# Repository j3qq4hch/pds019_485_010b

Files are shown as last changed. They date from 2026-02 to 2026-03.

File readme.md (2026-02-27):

# pds019_485_010

В этом репозитории содержатся исходники проекта `pds019_485_010`. Проект включает в себя две платы: A и B.

На плате А располагается модуль esp32, разъемы для его программирования две кнопки и несколько светодиодов.

На плате B располагается система питания устройства, состоящая из AC-DC модуля, создающего шину питания 12в и DC-DC конвертера 12в -> 3.3в. Кроме этого на плате B располагается гальванически изолированный RS485 интерфейс, реле и разъем для подключения датчика. 

# Плата А

<p align = center>
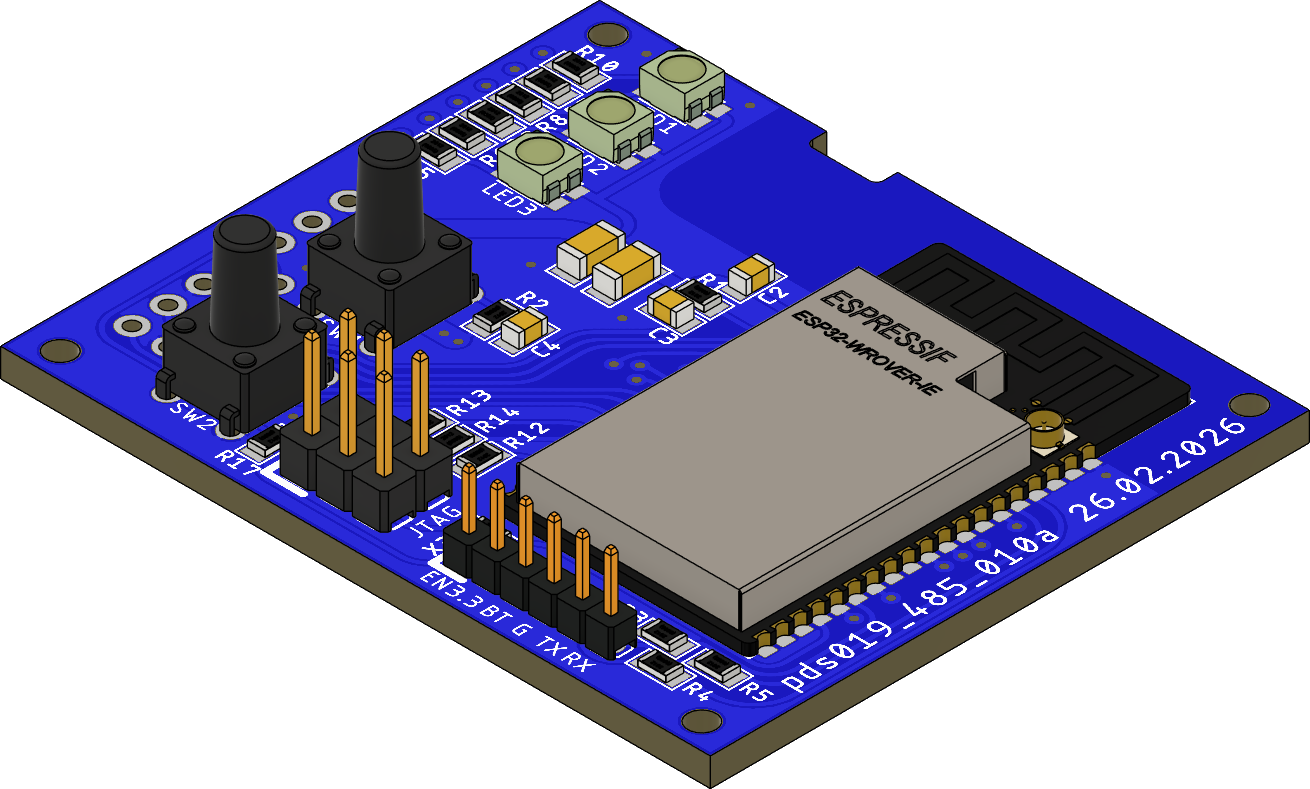
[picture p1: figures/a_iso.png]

</p>

# Плата B
<p align = center>

| Сторона TOP  | Сторона BOTTOM |
|---|---|
|||

</p>

3D модель доступна [по ссылке](https://a360.co/4bcfLyz).
BoM доступен [по ссылке](https://docs.google.com/spreadsheets/d/1rppHGotYg97vevn0TNhSlOjf3by5jG4KPH9rv6CT_tg/edit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).

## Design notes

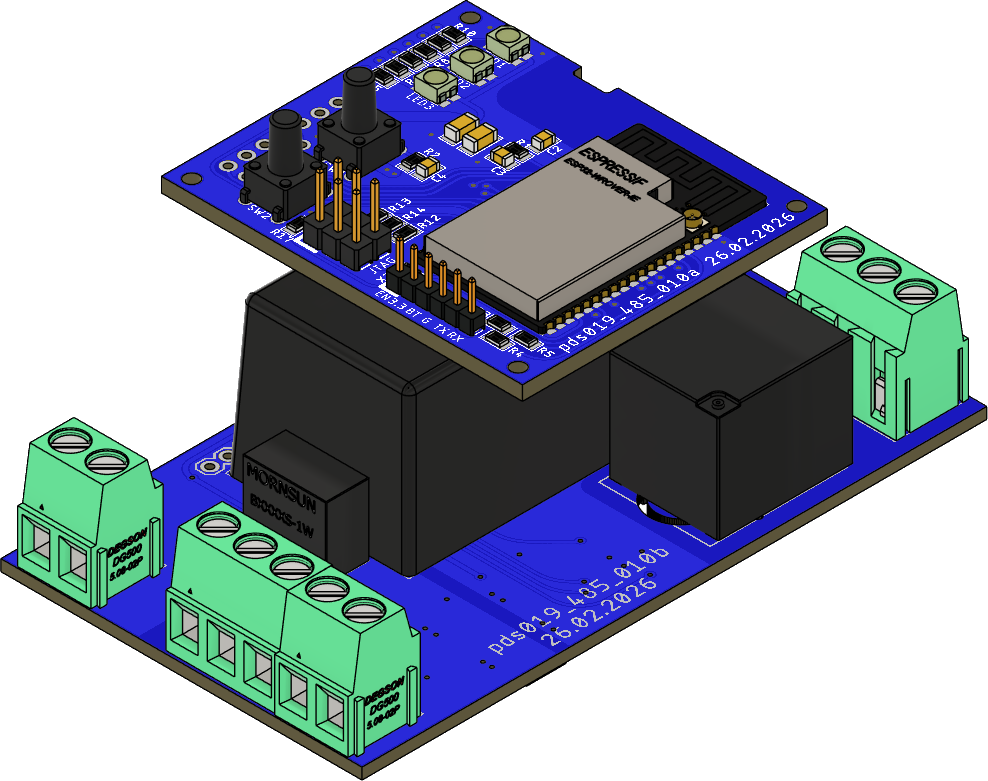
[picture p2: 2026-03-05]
figures/iso_assy.png

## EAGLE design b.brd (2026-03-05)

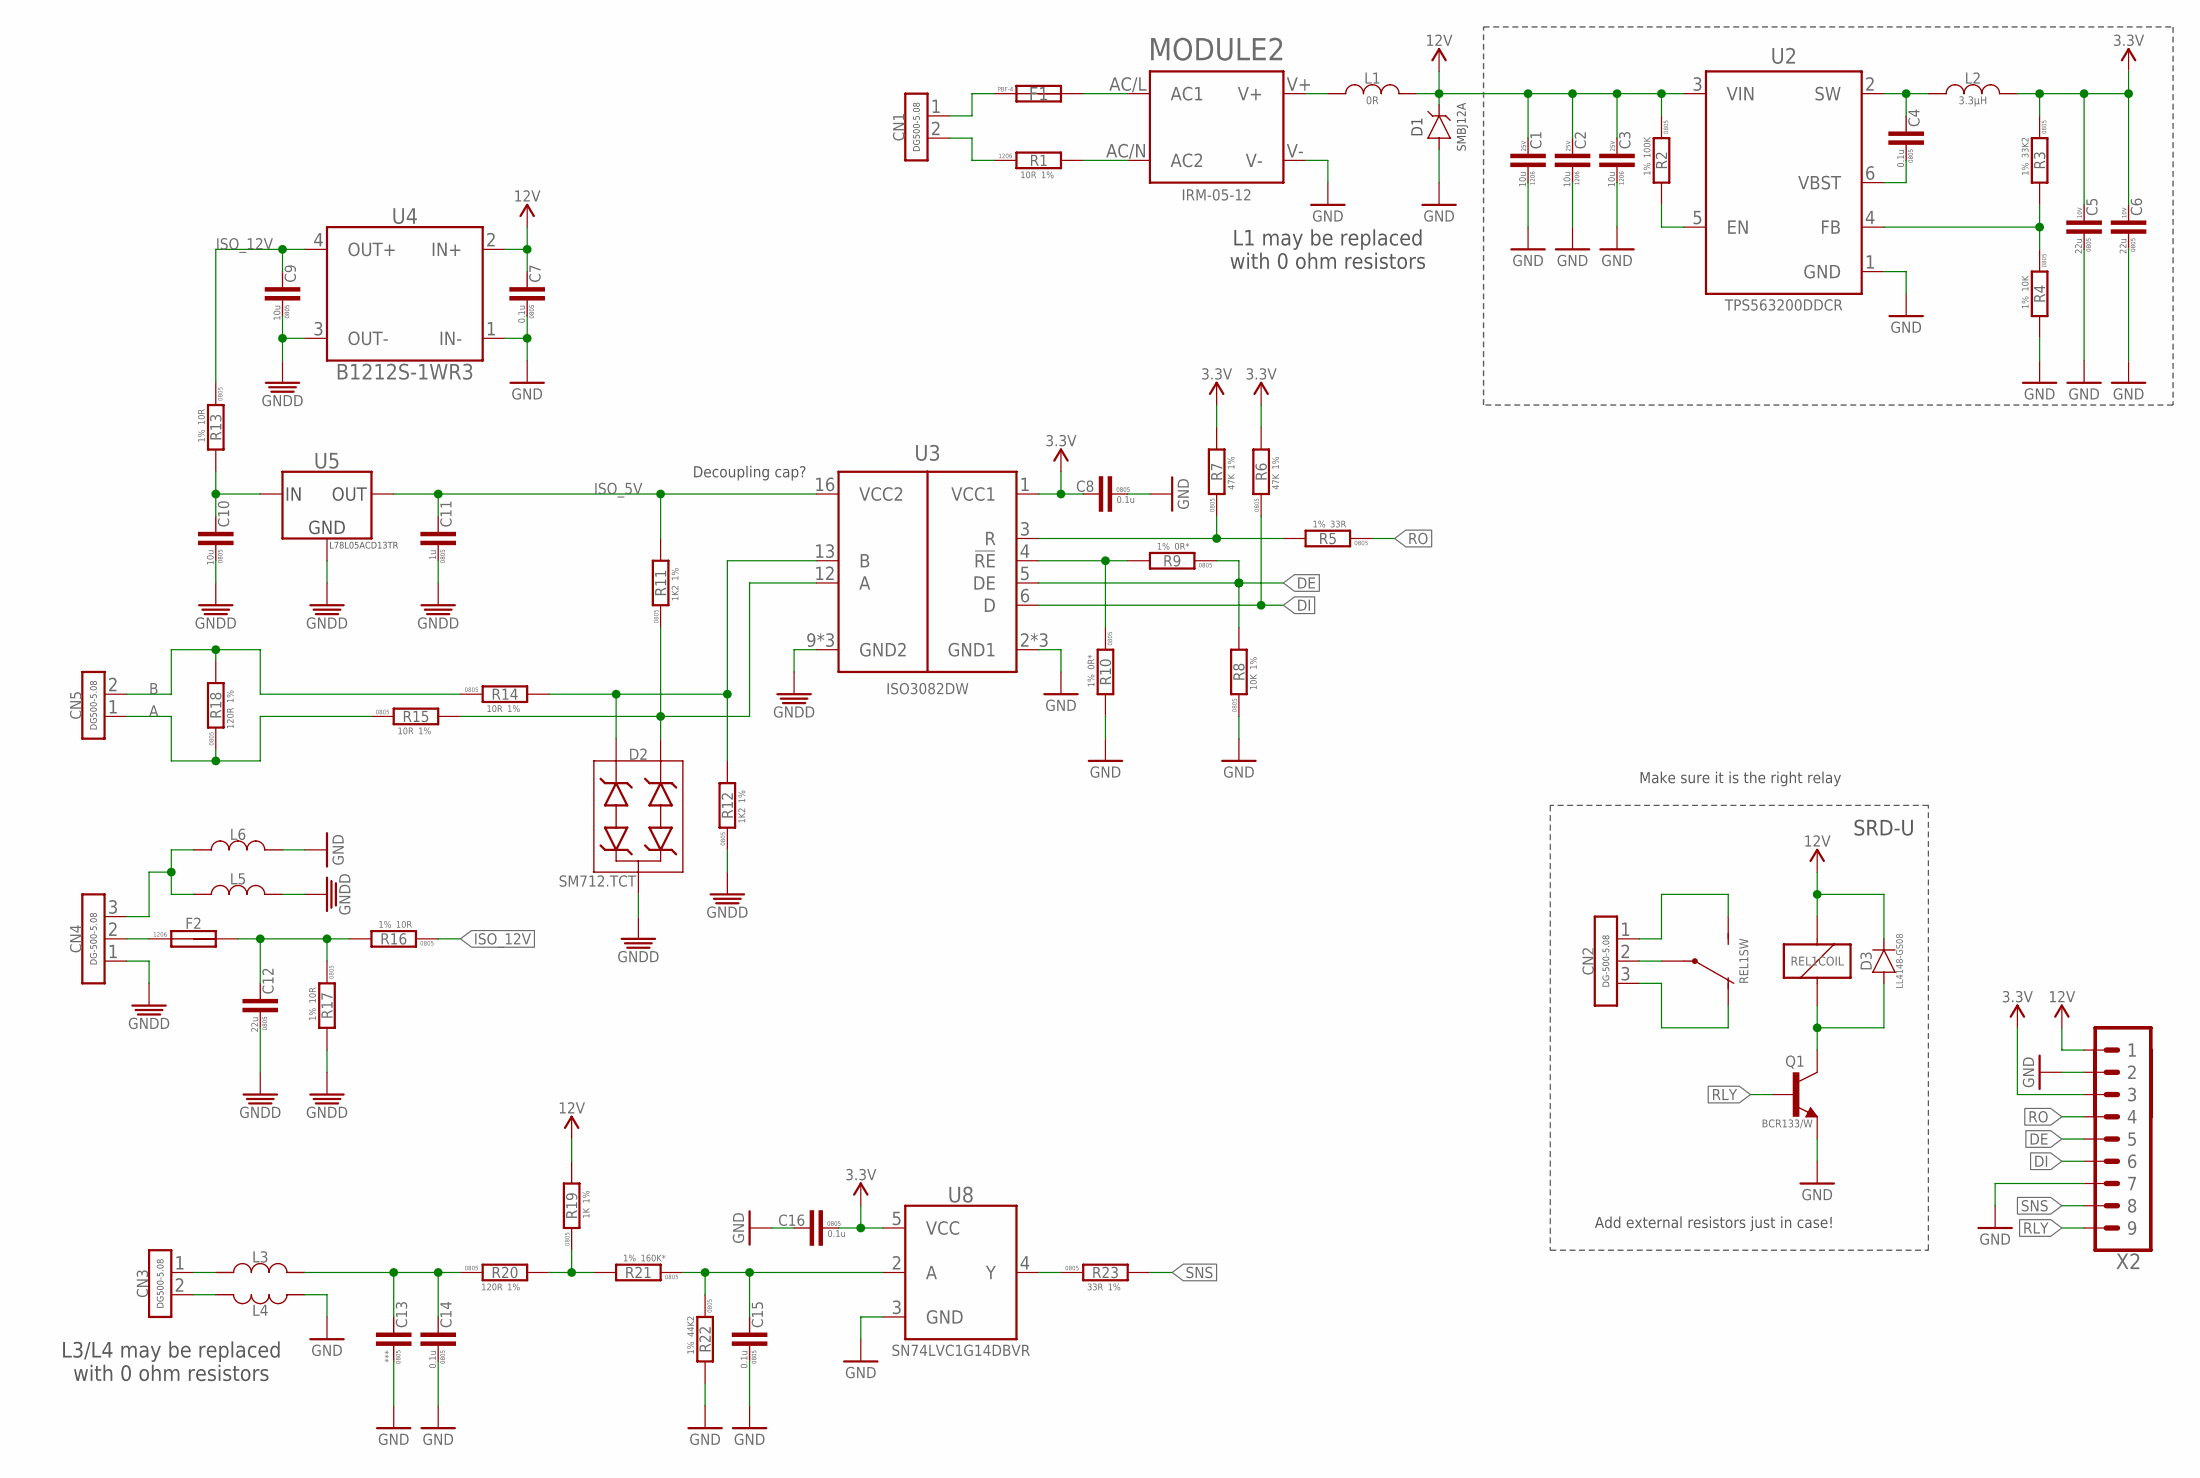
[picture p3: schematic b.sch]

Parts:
C1, C2, C3: 10u; C1206; VOLTAGE 25V
C4, C7, C8, C14, C15, C16: 0.1u; C0805
C5, C6: 22u; C0805; VOLTAGE 10V
C9, C10: 10u; C0805
C11: 1u; C0805
C12: 22u; C0805
C13: ***; C0805
CN1, CN3, CN5: CON-2P-DG500-5.08; DG500-5.08-02P
CN2, CN4: CON-3P-DG500-5.08; DG500-5.08-03P
D1: SMBJ12A-SMB; DO-214AA(SMB)
D2: SM712; SOT23B-3
D3: LL4148; LL-34
F1: 1.6A; MST-FUSE
F2: MF-NSMF050-2; F1206
L1: 0R; L0805
L2: 3.3µH; VLS6045EX
L3, L4, L5, L6: L-0805; L0805
MODULE2: IRM-05-12; IRM-05
Q1: BCR133; SOT23B-3
R1: 10R; R1206
R2: 100K; R0805
R3: 33K2; R0805
R4, R8: 10K; R0805
R5, R23: 33R; R0805
R6, R7: 47K; R0805
R9, R10: 0R*; R0805
R11, R12: 1K2; R0805
R13, R14, R15, R16, R17: 10R; R0805
R18, R20: 120R; R0805
R19: 1K; R0805
R21: 160K*; R0805
R22: 44K2; R0805
REL1: RELAY_SPDTHJR-3FF-SH; HJR-3FF-12VDC-S-Z
U2: TPS563200; SOT23-6
U3: ISO3082; SO-16W
U4: B1212S-1WR3; SIP-4
U5: L78L05ACD13TR; SOIC8
U8: 74LVC1G14DBV; SOT23-5
X2: PINHEAD_1X09-2.54-TH-MALE; 1X09-PTH-2.54

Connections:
3490587: R5.2, R7.1, U3.3 (R)
+12V: CN4.2, F2.P$1 (1)
A: CN5.1, R15.1, R18.1
B: CN5.2, R14.1, R18.2
DE: R8.2, R9.1, U3.5 (DE), X2.5
DI: R6.1, U3.6 (D), X2.6
GND: C1.P$1 (1), C2.P$1 (1), C3.P$1 (1), C5.1, C6.1, C7.1, C8.1, C13.1, C14.1, C15.1, C16.2, D1.A, L4.2, L6.1, MODULE2.V-, Q1.2 (E), R4.2, R8.1, R10.2, R22.2, U2.1 (GND), U3.2 (GND1), U3.7 (GND1), U3.8 (GND1), U4.1 (IN-), U8.3 (GND), X2.2, X2.7
GNDD: C9.1, C10.1, C11.1, C12.1, CN4.1, D2.3, L5.2, R12.1, R17.2, U3.9 (GND2), U3.10 (GND2), U3.15 (GND2), U4.3 (OUT-), U5.2 (GND), U5.3 (GND), U5.6 (GND), U5.7 (GND)
ISO_5V: C11.2, R11.2, U3.16 (VCC2), U5.1 (OUT)
ISO_12V: C9.2, R13.1, R16.1, U4.4 (OUT+)
unnamed: CN4.3, L5.1, L6.2
unnamed: MODULE2.AC/N (AC2), R1.P$2 (2)
unnamed: D2.2 (C2), R11.1, R15.2, U3.12 (A)
unnamed: D2.1 (C3), R12.2, R14.2, U3.13 (B)
unnamed: F1.2, MODULE2.AC/L (AC1)
unnamed: L1.1, MODULE2.V+
unnamed: C4.1, U2.6 (VBST)
unnamed: R9.2, R10.1, U3.4 (!RE)
unnamed: CN1.1, F1.1
unnamed: CN1.2, R1.P$1 (1)
unnamed: R2.2, U2.5 (EN)
unnamed: C4.2, L2.P$1 (1), U2.2 (SW)
unnamed: R3.2, R4.1, U2.4 (FB)
unnamed: CN2.2, REL1.1 (COM)
unnamed: CN2.3, REL1.4 (NC)
unnamed: CN2.1, REL1.3 (NO)
unnamed: CN3.1, L3.1
unnamed: CN3.2, L4.1
unnamed: C13.2, C14.2, L3.2, R20.1
unnamed: C10.2, R13.2, U5.8 (IN)
unnamed: R19.1, R20.2, R21.2
unnamed: C15.2, R21.1, R22.1, U8.2 (A)
unnamed: D3.A, Q1.3 (C), REL1.5 (2)
unnamed: R23.1, U8.4 (Y)
unnamed: C12.2, F2.P$2 (2), R16.2, R17.1
RLY: Q1.1 (B), X2.9
RO: R5.1, X2.4
SNS: R23.2, X2.8
VDD_3V3: C5.2, C6.2, C8.2, C16.1, L2.P$2 (2), R3.1, R6.2, R7.2, U3.1 (VCC1), U8.5 (VCC), X2.3
VDD_12V: C1.P$2 (2), C2.P$2 (2), C3.P$2 (2), C7.2, D1.C, D3.C, L1.2, R2.1, R19.2, REL1.2 (1), U2.3 (VIN), U4.2 (IN+), X2.1

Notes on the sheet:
Add external resistors just in case!
Make sure it is the right relay
Decoupling cap?
SRD-U
L3/L4 may be replaced with 0 ohm resistors
L1 may be replaced with 0 ohm resistors

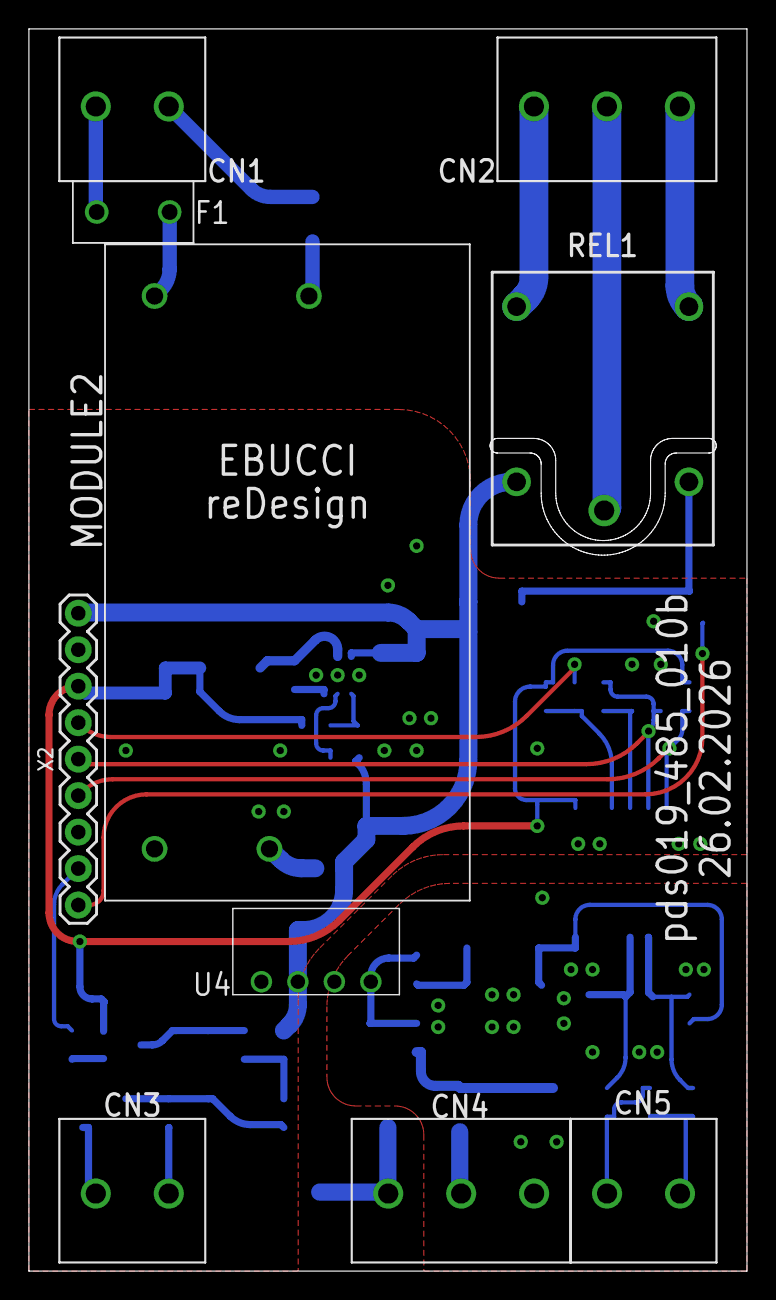
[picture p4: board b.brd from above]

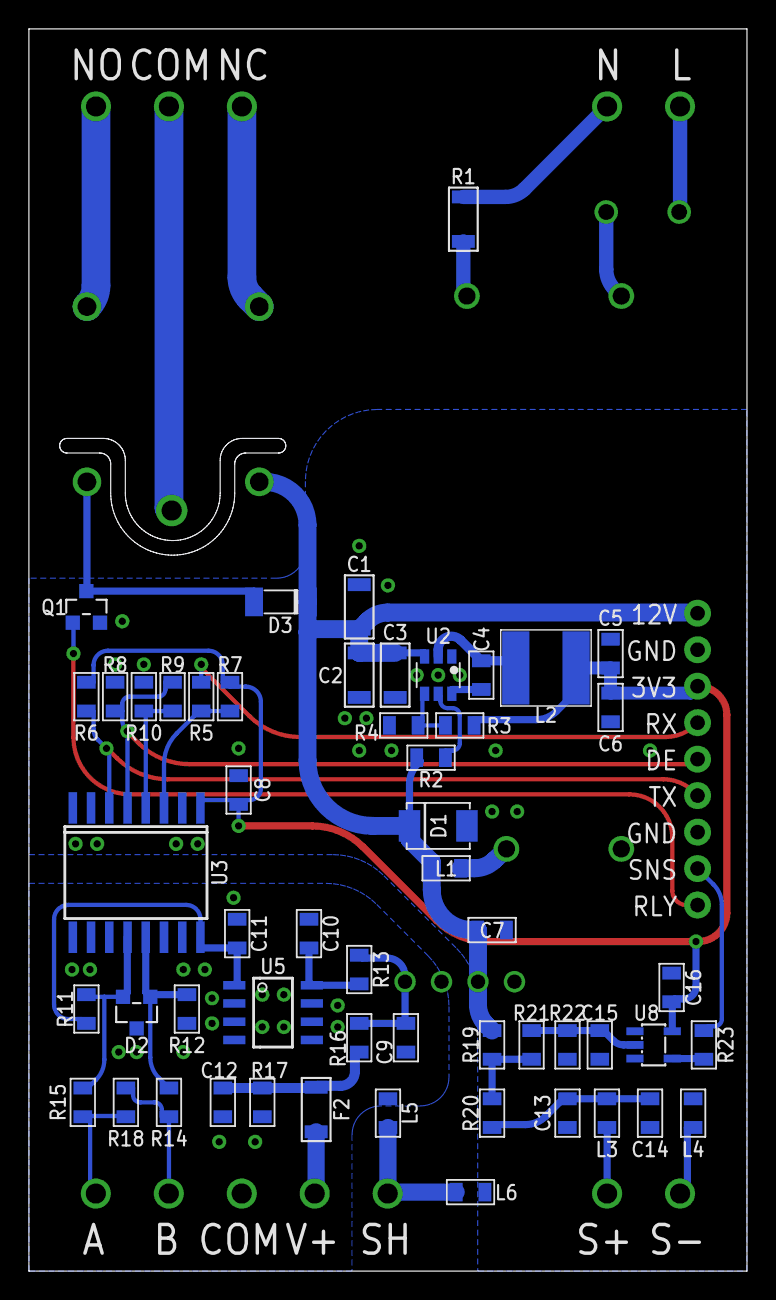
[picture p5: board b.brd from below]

Board: 2 copper layers, 50.0 x 86.5 mm, 65 parts (54 on the bottom side), 40 nets.

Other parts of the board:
U$1: REF_B

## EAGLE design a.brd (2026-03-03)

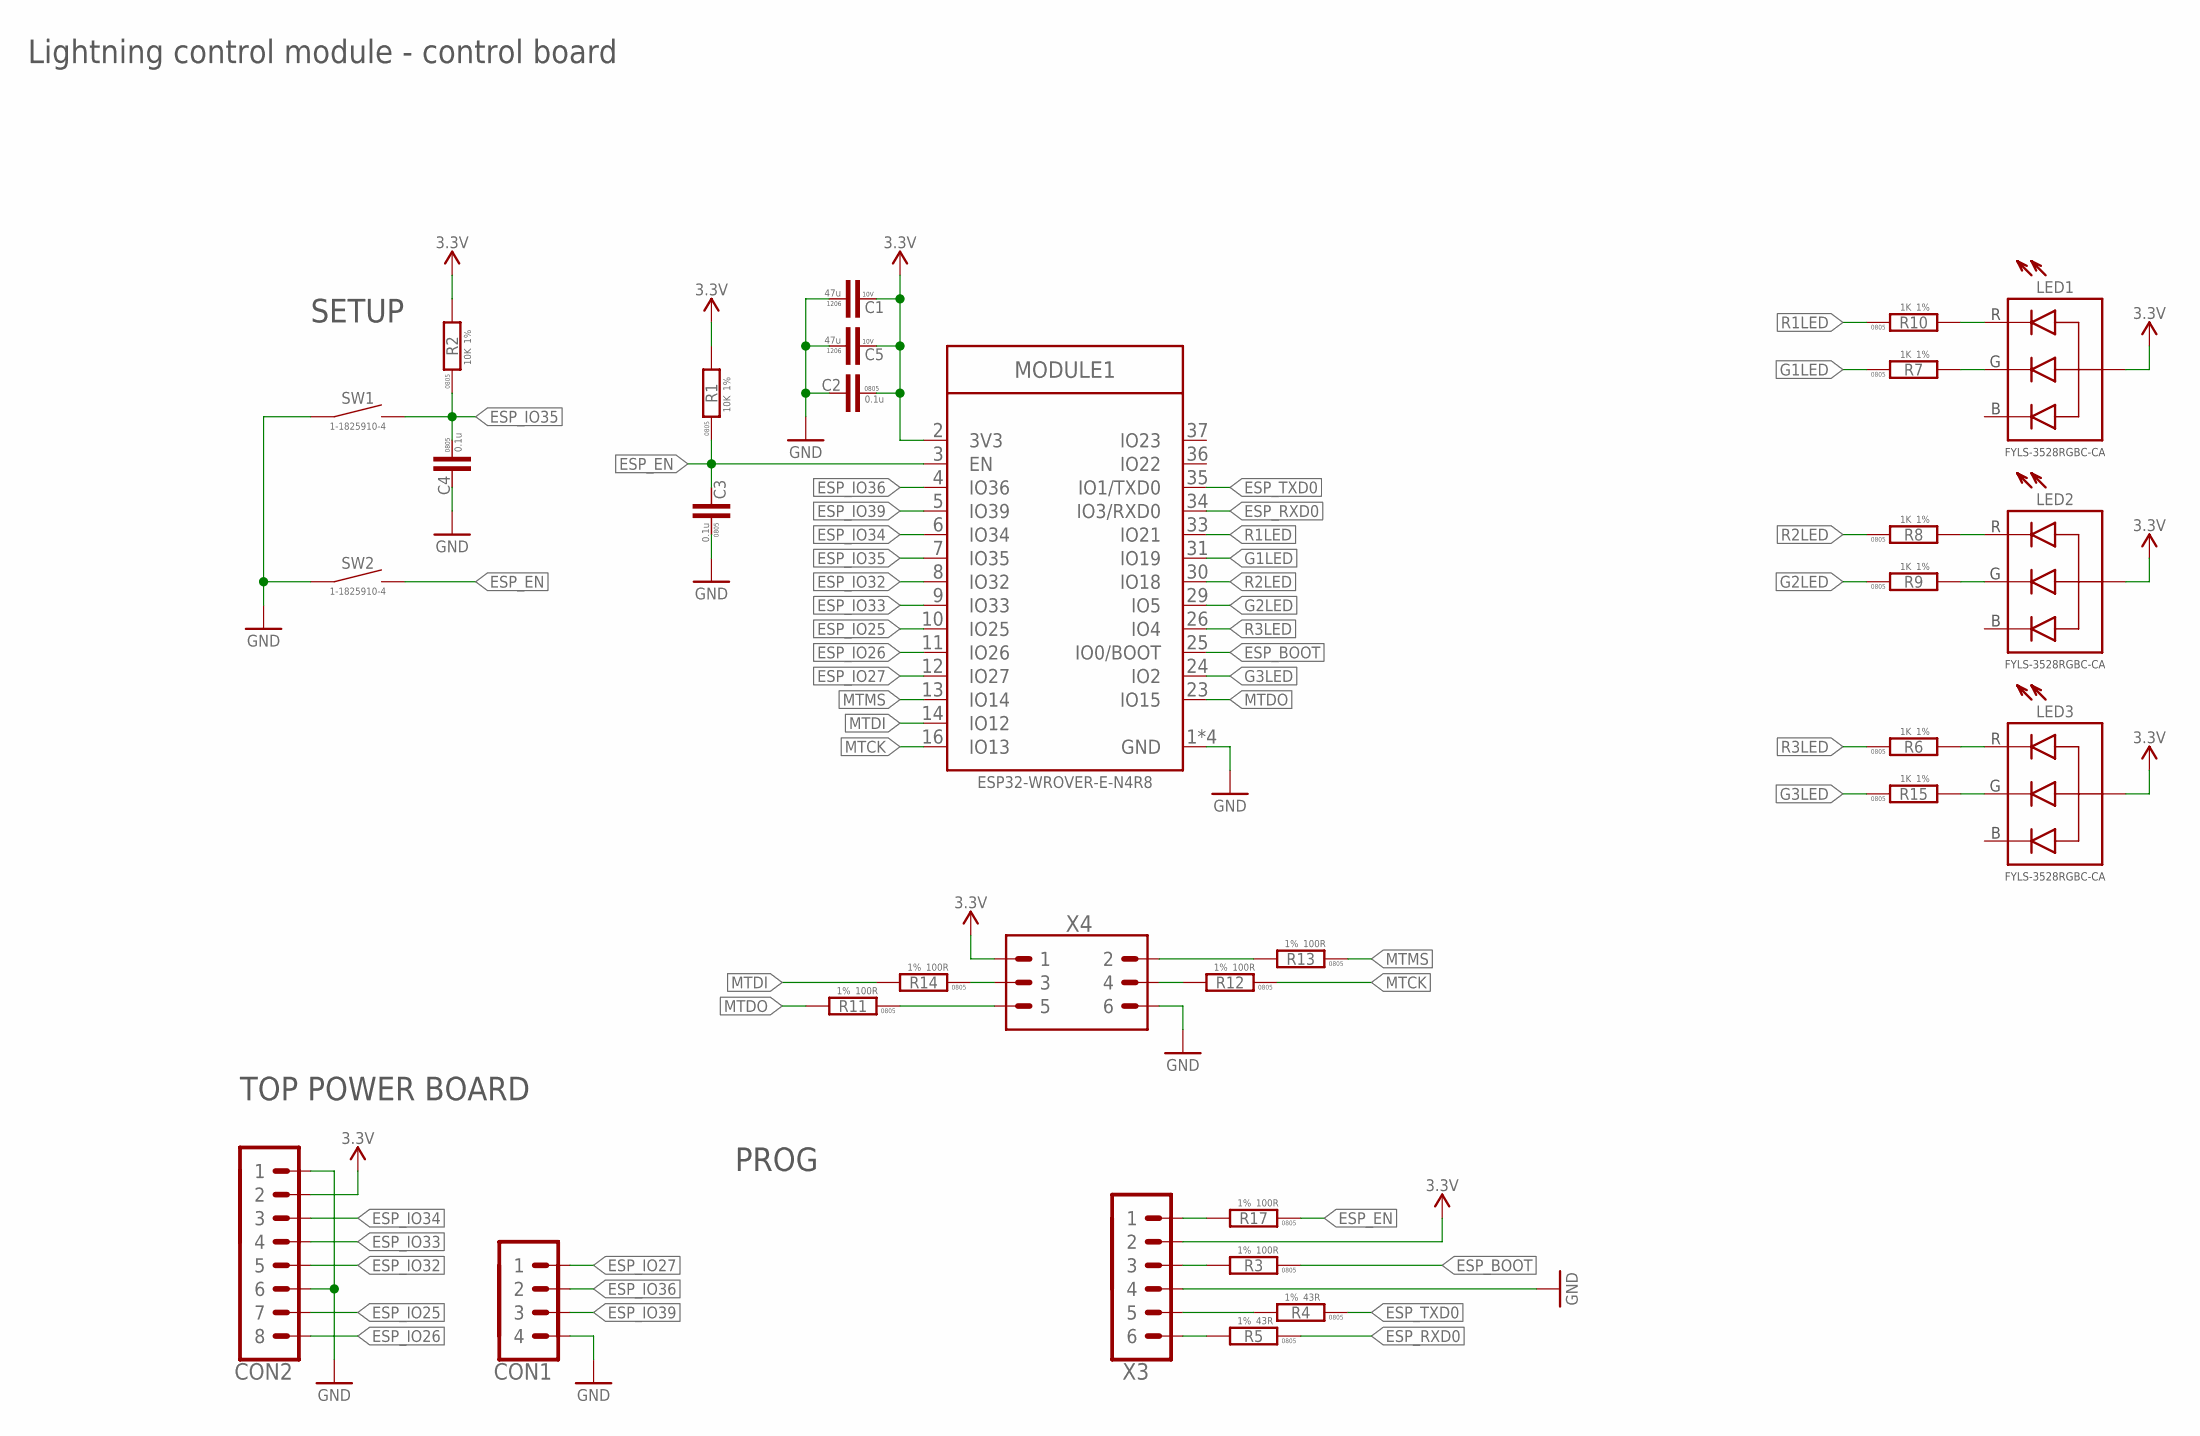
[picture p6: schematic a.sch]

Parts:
C1, C5: 47u; C1206; VOLTAGE 10V
C2, C3, C4: 0.1u; C0805
CON1: PINHEAD_1X04-2.54; 1X04-PTH-2.54
CON2: PINHEAD_1X08-2.54; 1X08-PTH-2.54
LED1, LED2, LED3: LED_RGB-3528; LED3528
MODULE1: ESP32-WROVER-(I)E; ESP32-WROVER-E
R1, R2: 10K; R0805
R3, R11, R12, R13, R14, R17: 100R; R0805
R4, R5: 43R; R0805
R6, R7, R8, R9, R10, R15: 1K; R0805
SW1, SW2: TACT_SWITCH-1-1825910-4; 1-1825910-4
X3: PINHEAD_1X06-2-MALE; 1X06-PTH-2
X4: PINHEAD_2X03-PTH-2.54; 2X03-PTH-2.54

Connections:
ESP_BOOT: MODULE1.25 (IO0/BOOT), R3.1
ESP_EN: C3.2, MODULE1.3 (EN), R1.1, R17.1, SW2.3 (2), SW2.4 (2)
ESP_IO25: CON2.7, MODULE1.10 (IO25)
ESP_IO26: CON2.8, MODULE1.11 (IO26)
ESP_IO27: CON1.1, MODULE1.12 (IO27)
ESP_IO32: CON2.5, MODULE1.8 (IO32)
ESP_IO33: CON2.4, MODULE1.9 (IO33)
ESP_IO34: CON2.3, MODULE1.6 (IO34)
ESP_IO35: C4.1, MODULE1.7 (IO35), R2.1, SW1.3 (2), SW1.4 (2)
ESP_IO36: CON1.2, MODULE1.4 (IO36)
ESP_IO39: CON1.3, MODULE1.5 (IO39)
ESP_RXD0: MODULE1.34 (IO3/RXD0), R5.1
ESP_TXD0: MODULE1.35 (IO1/TXD0), R4.1
G1LED: MODULE1.31 (IO19), R7.1
G2LED: MODULE1.29 (IO5), R9.1
G3LED: MODULE1.24 (IO2), R15.1
GND: C1.P$1 (1), C2.2, C3.1, C4.2, C5.P$1 (1), CON1.4, CON2.1, CON2.6, MODULE1.1 (GND), MODULE1.15 (GND), MODULE1.38 (GND), MODULE1.39 (GND), SW1.1, SW1.2 (1), SW2.1, SW2.2 (1), X3.4, X4.6
MTCK: MODULE1.16 (IO13), R12.1
MTDI: MODULE1.14 (IO12), R14.2
MTDO: MODULE1.23 (IO15), R11.2
MTMS: MODULE1.13 (IO14), R13.1
unnamed: LED2.1 (R), R8.2
unnamed: R13.2, X4.2
unnamed: R5.2, X3.6
unnamed: R4.2, X3.5
unnamed: R3.2, X3.3
unnamed: R12.2, X4.4
unnamed: LED1.1 (R), R10.2
unnamed: LED1.4 (G), R7.2
unnamed: LED2.4 (G), R9.2
unnamed: LED3.1 (R), R6.2
unnamed: LED3.4 (G), R15.2
unnamed: R14.1, X4.3
unnamed: R11.1, X4.5
unnamed: R17.2, X3.1
R1LED: MODULE1.33 (IO21), R10.1
R2LED: MODULE1.30 (IO18), R8.1
R3LED: MODULE1.26 (IO4), R6.1
VDD_3V3: C1.P$2 (2), C2.1, C5.P$2 (2), CON2.2, LED1.2 (A), LED2.2 (A), LED3.2 (A), MODULE1.2 (3V3), R1.2, R2.2, X3.2, X4.1

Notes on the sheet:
Lightning control module - control board
SETUP
PROG
TOP POWER BOARD

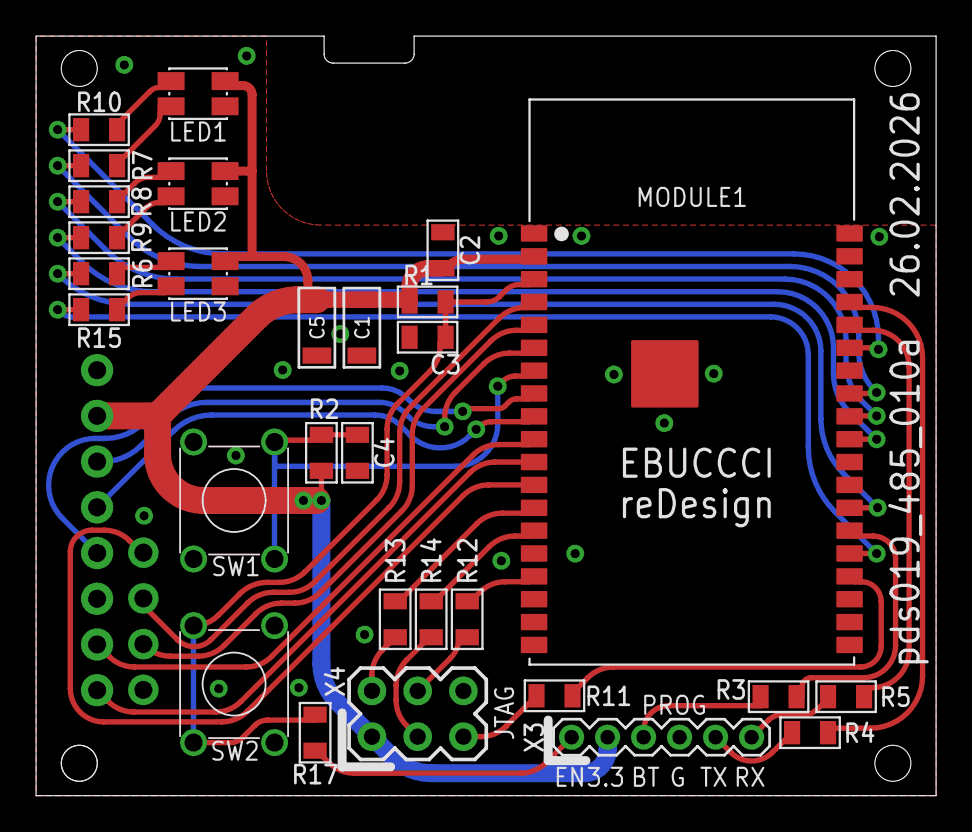
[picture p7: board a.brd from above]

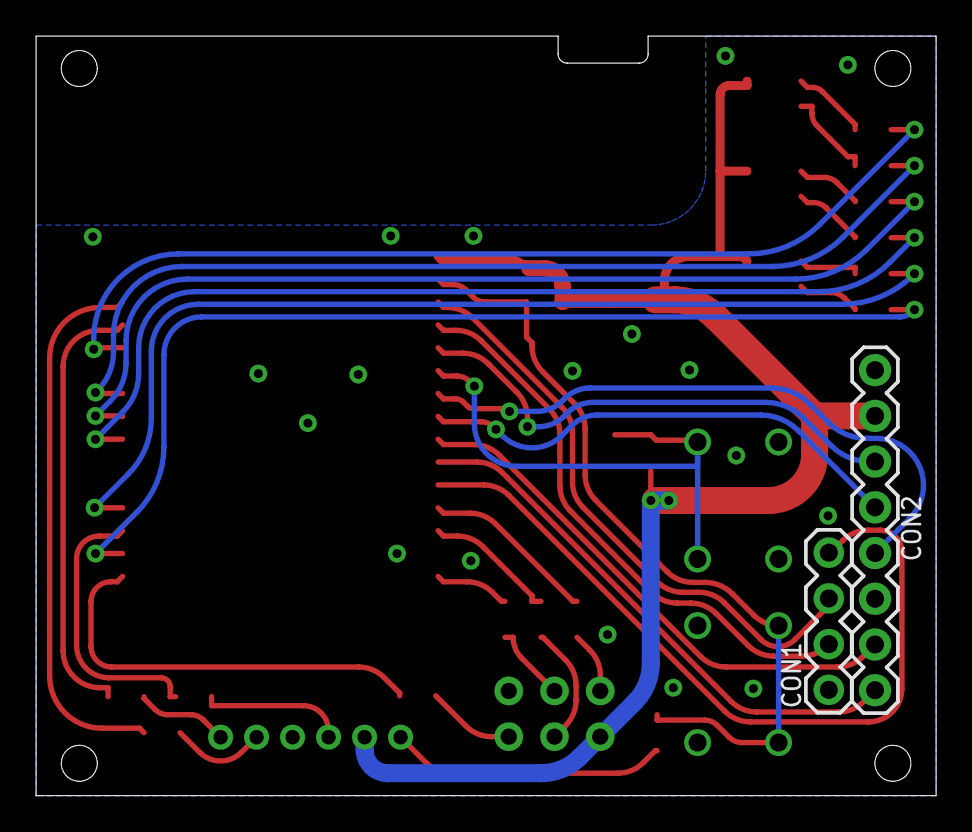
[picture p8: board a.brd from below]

Board: 2 copper layers, 50.0 x 42.2 mm, 32 parts (2 on the bottom side), 39 nets.

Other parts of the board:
U$1: REF_A

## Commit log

2026-03-03 preRelease minor fixes
    [a.brd, a.sch, b.brd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]
2026-03-05 Notes and pictures update
    [b.brd, b.sch]
